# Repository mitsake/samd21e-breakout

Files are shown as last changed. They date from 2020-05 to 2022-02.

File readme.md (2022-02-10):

# Small SAMD21 breakout

This is a small, simple breakout for the Microchip (formerly Atmel) [ATSAMD21E][] series of chips in the TQFP package. I designed it mostly for something to do while locked down at home, but also so that I could use the bare ICs I had spare from previous projects.

[ATSAMD21E]: https://www.microchip.com/wwwproducts/en/ATSAMD21E18

Most I/O pins are broken out, with the exception of PA00/01 (XIN32 and XOUT32 for the watch crystal) and PA24/25 (D- and D+ for USB). The SWD interface is available via either the header, or through the [SOICbite][] connector opposite the USB footprint. There's an onboard regulator, crystal, reset button, and USB jack make things a bit more convenient. 

This design is based on Adafruit's [Trinket M0][] as well as Technoblogy's Minimal [ATSAMD21 Computer][minimalcomp].

[SOICbite]: https://github.com/SimonMerrett/SOICbite/
[Trinket M0]: https://www.adafruit.com/product/3500
[minimalcomp]: http://www.technoblogy.com/show?2833

## BoM

| Reference | Quantity | Value | Footprint |
| --- | --- | --- | --- |
| C1, C2 | 2 | 10 μF, > 6 V | 0603 |
| C3, C4 | 2 | 1 μF, > 4 V | 0603 |
| C5 | 1 | 0.1 μF, > 4 V | 0603 |
| C6, C7 | 2 | 10 pF, > 4 V | 0603 |
| J1 | 1 | Micro-USB jack | [Molex 105017-0001][1] |
| SW1 | 1 | Push switch | [Alps SKRKAEE020][2] |
| U1 | 1 | AP2112K-3.3 | SOT23-5 |
| U2 | 1 | ATSAMD21Exx | TQFP-32 |
| Y1 | 1 | 32.768 kHz, < 12.5 pF load | [Micro Crystal CM7V-T1A][3] |

[1]: https://www.molex.com/molex/products/part-detail/io_connectors/1050170001
[2]: https://tech.alpsalpine.com/prod/e/html/tact/surfacemount/skrk/skrk_list.html
[3]: https://www.microcrystal.com/en/products/khz-quartz-crystals/cm7v-t1a/

## Schematic

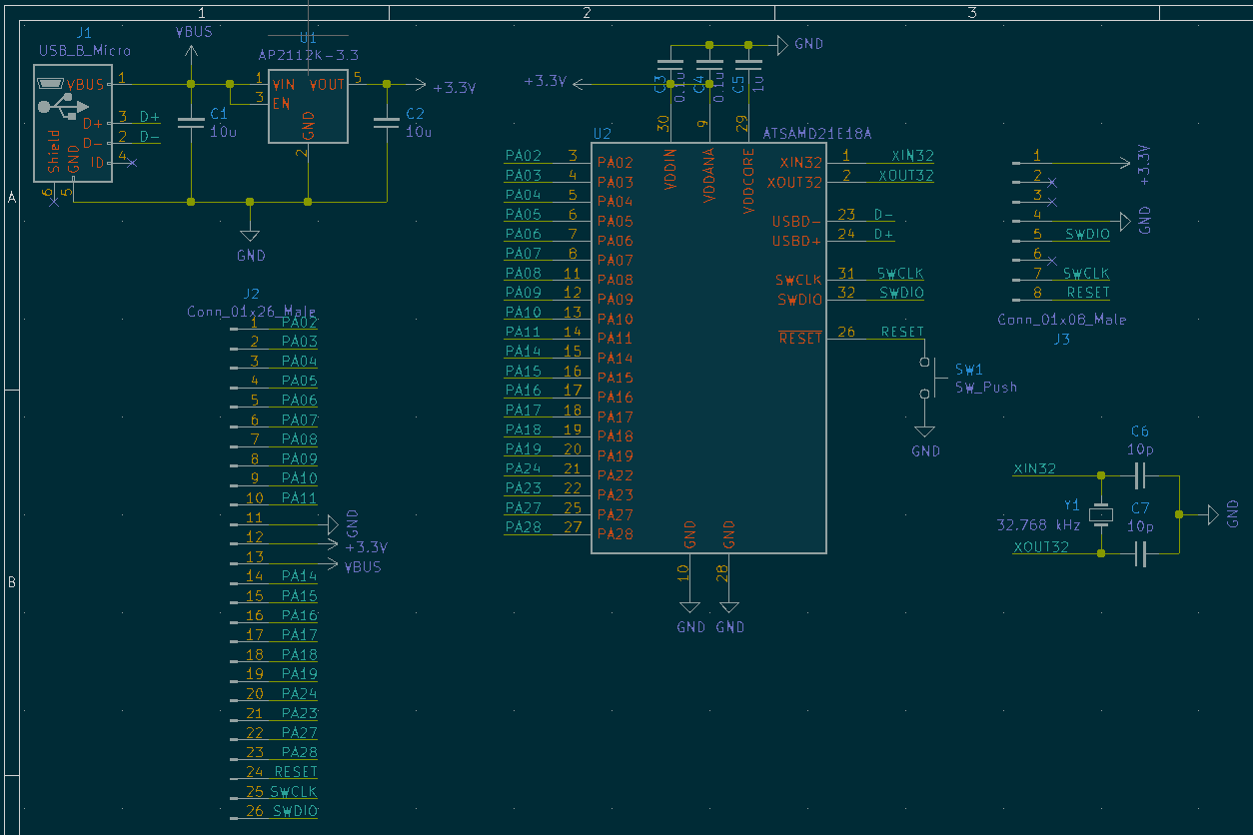
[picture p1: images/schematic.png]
KiCad schematic for a breakout board


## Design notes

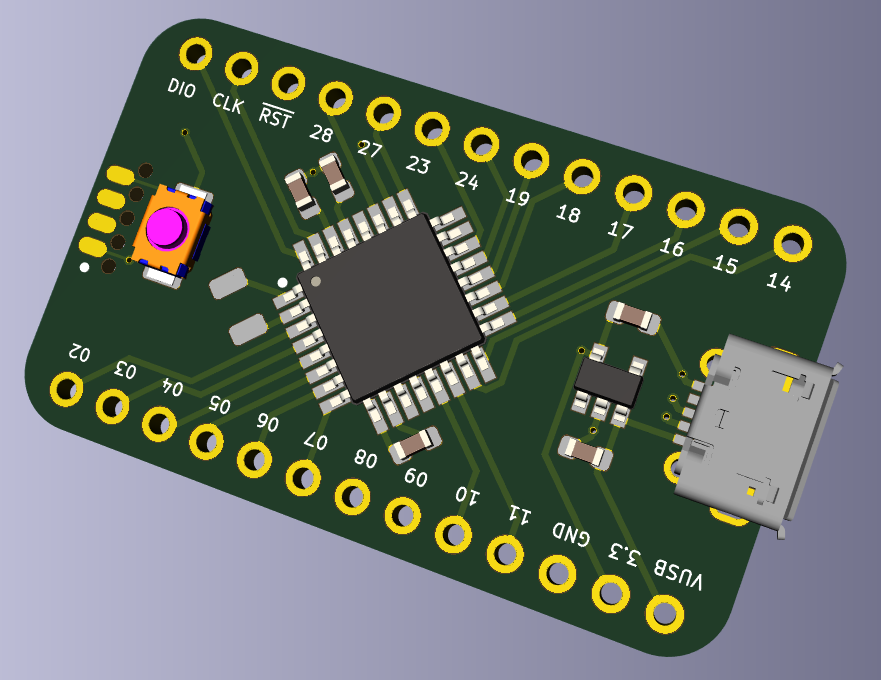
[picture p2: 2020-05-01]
images/render.png

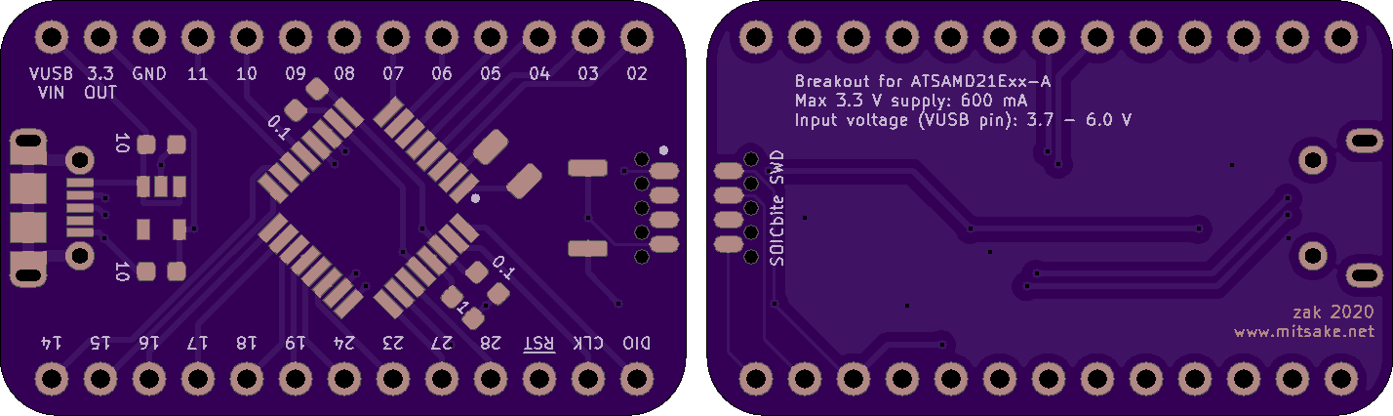
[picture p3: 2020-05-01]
images/samdbreakout.png

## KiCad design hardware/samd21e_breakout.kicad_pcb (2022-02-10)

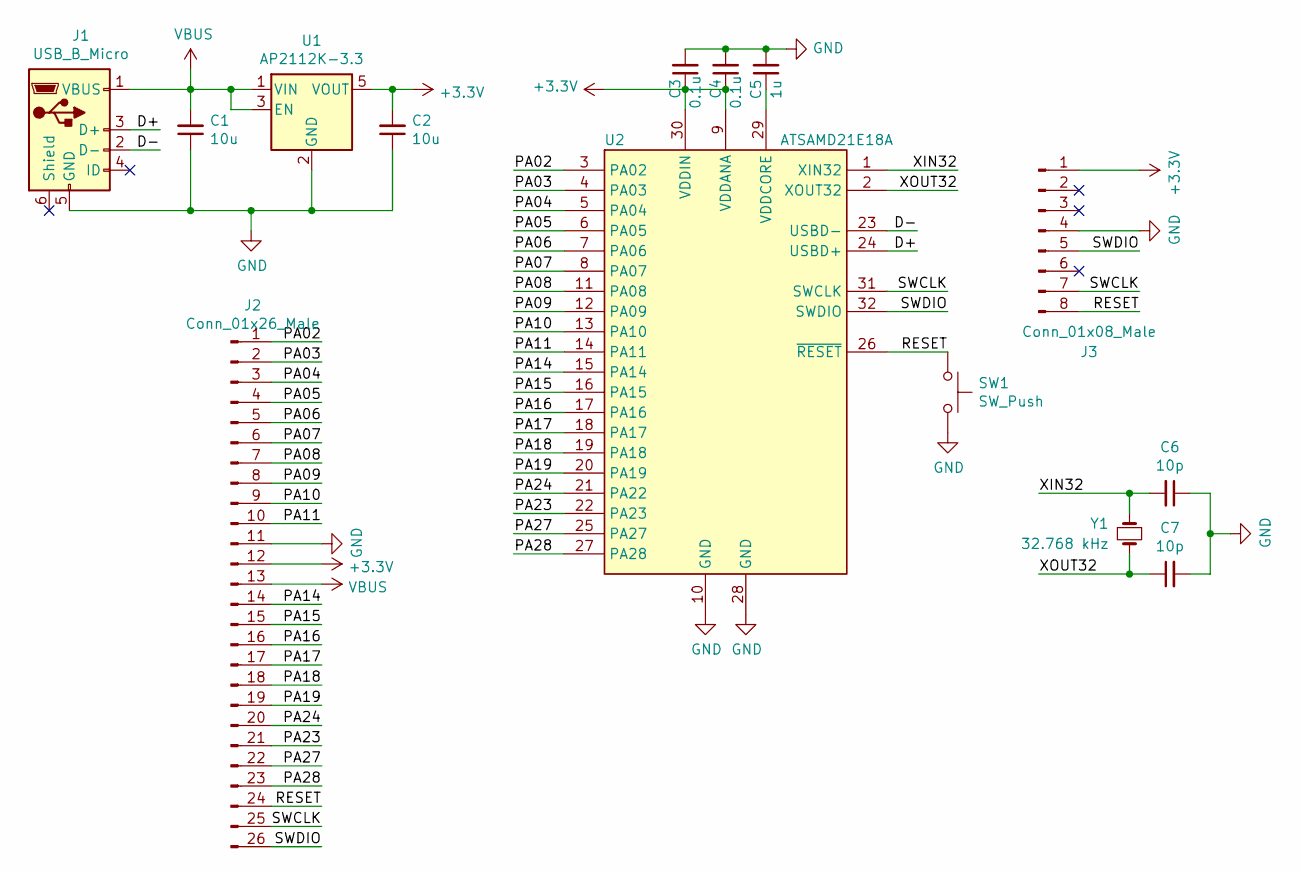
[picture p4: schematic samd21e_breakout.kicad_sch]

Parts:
C1, C2: 10u; C_0603_NoSilk
C3, C4: 0.1u; C_0603_NoSilk
C5: 1u; C_0603_NoSilk
C6, C7: 10p; C_0603_NoSilk
J1: USB_B_Micro; Molex-105017-0001
J2: Conn_01x26_Male; PinHeader_2x13_Breadboard_Spaced
J3: Conn_01x08_Male; SOIC_clipProgSmall
SW1: SW_Push; SW_Push_Alps_SKRK_NoSilk
U1: AP2112K-3.3; SOT-23-5_NoSilk
U2: ATSAMD21E18A; TQFP-32_NoSilk
Y1: 32.768 kHz; CM7V-T1A

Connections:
+3V3: C2.2, C3.1, C4.1, J2.12, J3.1, U1.5 (VOUT), U2.9 (VDDANA), U2.30 (VDDIN)
/D+: J1.3 (D+), U2.24 (USBD+)
/D-: J1.2 (D-), U2.23 (USBD-)
/PA02: J2.1, U2.3 (PA02)
/PA03: J2.2, U2.4 (PA03)
/PA04: J2.3, U2.5 (PA04)
/PA05: J2.4, U2.6 (PA05)
/PA06: J2.5, U2.7 (PA06)
/PA07: J2.6, U2.8 (PA07)
/PA08: J2.7, U2.11 (PA08)
/PA09: J2.8, U2.12 (PA09)
/PA10: J2.9, U2.13 (PA10)
/PA11: J2.10, U2.14 (PA11)
/PA14: J2.14, U2.15 (PA14)
/PA15: J2.15, U2.16 (PA15)
/PA16: J2.16, U2.17 (PA16)
/PA17: J2.17, U2.18 (PA17)
/PA18: J2.18, U2.19 (PA18)
/PA19: J2.19, U2.20 (PA19)
/PA23: J2.21, U2.22 (PA23)
/PA24: J2.20, U2.21 (PA22)
/PA27: J2.22, U2.25 (PA27)
/PA28: J2.23, U2.27 (PA28)
/RESET: J2.24, J3.8, SW1.1, U2.26 (~RESET)
/SWCLK: J2.25, J3.7, U2.31 (SWCLK)
/SWDIO: J2.26, J3.5, U2.32 (SWDIO)
/XIN32: C6.2, U2.1 (XIN32), Y1.1
/XOUT32: C7.1, U2.2 (XOUT32), Y1.2
GND: C1.1, C2.1, C3.2, C4.2, C5.2, C6.1, C7.2, J1.5 (GND), J2.11, J3.4, SW1.2, U1.2 (GND), U2.10 (GND), U2.28 (GND)
unnamed: C5.1, U2.29 (VDDCORE)
VBUS: C1.2, J1.1 (VBUS), J2.13, U1.1 (VIN), U1.3 (EN)

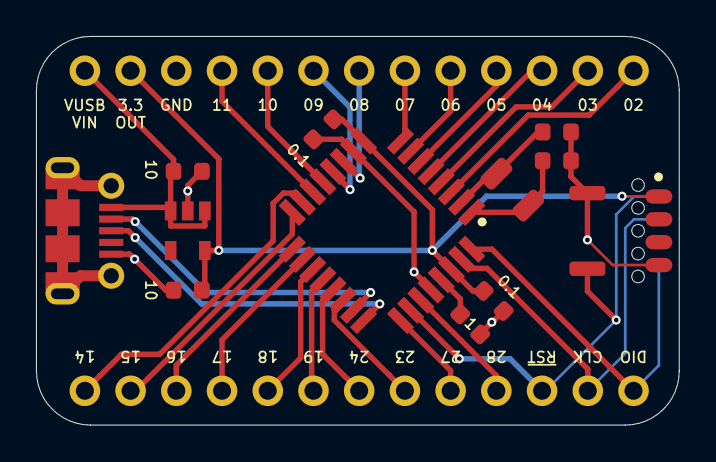
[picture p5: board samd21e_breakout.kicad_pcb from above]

Board: 2 copper layers, 35.7 x 21.6 mm, 14 parts (0 on the bottom side), 31 nets.

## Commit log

2020-06-12 added load capacitors to schematic and pcb
    [samd21e_breakout.kicad_pcb, samd21e_breakout.sch]
2020-06-12 updated schematic image
2022-02-10 Long overdue update to readme, upgrade to KiCad 6
    [samd21e_breakout.kicad_pcb, samd21e_breakout.kicad_sch]
